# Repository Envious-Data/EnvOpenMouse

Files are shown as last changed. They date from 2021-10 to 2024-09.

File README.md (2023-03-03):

# EnvOpenMouse
 An Open-source mouse for the UK market.
 
### Why?

A lot of friends of mine would like something like a ploopyco mouse but there arent such options avaliable here in the UK and even then custom mouses as a whole is just not very popular.

This will be a open source mouse utilizting the PMW3360 and RP2040.

- Why the RP2040? Why not I say
- Why PMW3360 - its easiest to get and is well known by the community meaning resources are avaliable.

### To do
- Need to verify fit of everything
- firmware
- 3d printable housing
- housing/shell maybe can be made of other matierals
- perhaps write a guide on how to order and get everything made
- contact some vendors to sell this through for those who dont want self assembly

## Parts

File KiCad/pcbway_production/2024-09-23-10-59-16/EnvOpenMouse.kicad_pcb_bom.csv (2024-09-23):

Designator | Quantity | Value | Footprint | Package | MPN | DNP | Mount_Type | LCSC | Description | MANUFACTURER
C1, C4 | 2 | 22pf 0402 | C_0402_1005Metric |  |  |  | smt
C10, C11, C14, C15, C16, C17, C18, C19, C20, C7, C8 | 11 | 100nf 0402 | C_0402_1005Metric |  |  |  | smt
C12, C13, C6 | 3 | 1uf 0402 | C_0402_1005Metric |  |  |  | smt
C2 | 1 | 10uf 0402 6.3V | C_0402_1005Metric |  |  |  | smt
C3 | 1 | 10uf 0402 | C_0402_1005Metric |  |  |  | smt
C5 | 1 | 0.1uf 0402 | C_0402_1005Metric |  |  |  | smt
C9 | 1 | 4.7uf 0402 | C_0402_1005Metric |  |  |  | smt
D1 | 1 | 1n5819W | D_SOD-123 |  |  |  | smt
FLASH1 | 1 | W25Q16JVUXIQ | SON-8-1EP_3x2mm_P0.5mm_EP1.4x1.6mm |  |  |  | smt
H1, H2, H3, H4, H5, H5, H6, H6, H7, H8 | 10 | MountingHole_Pad | MountingHole_2.2mm_M2 |  |  |  | tht
J1, J3 | 2 | B3U-1000P | SW_Push_SPST_NO_Alps_SKRK |  |  |  | smt
J10, J12, J13, J14, J15, J9 | 6 | 0.8mm BM03B | JST_SUR_BM03B-SURS-TF_1x03-1MP_P0.80mm_Vertical |  |  |  | smt
J11 | 1 | Conn_02x02 Pins | PinHeader_1x02_P1.27mm_Vertical |  |  |  | tht
J16 | 1 | Conn_01x14 | PinHeader_1x14_P1.00mm_Vertical |  |  |  | tht |  | Generic connector, single row, 01x14, script generated (kicad-library-utils/schlib/autogen/connector/)
J2 | 1 | Conn_01x03 | PinHeader_1x03_P1.27mm_Vertical |  |  |  | tht
J4 | 1 | Conn_02x02 Socket | PinSocket_1x02_P1.27mm_Vertical |  |  |  | tht
J5, J6 | 2 | Conn_02x02 Socket | PinSocket_2x02_P1.27mm_Vertical |  |  |  | tht
J7, J8 | 2 | Conn_02x02 Pins | PinHeader_2x02_P1.27mm_Vertical |  |  |  | tht
R1 | 1 | 39 ohm 0402 | R_0402_1005Metric |  |  |  | smt
R10 | 1 | 27Ohms 0402 Resistor | C_0402_1005Metric |  |  |  | smt
R2, R6 | 2 | 1K 0402 | R_0402_1005Metric |  |  |  | smt
R3 | 1 | 10k 0402 | R_0402_1005Metric |  |  |  | smt
R4, R7 | 2 | 10K 0402 | R_0402_1005Metric |  |  |  | smt
R5, R8 | 2 | 5.1K | R_0402_1005Metric |  |  |  | smt
R9 | 1 | 27Ohms 0402 Resistor | C_0402_1005Metric |  |  |  | smt
SW1, SW2, SW3 | 3 | Kailh GM switch | MouseSwitch |  |  |  | tht
SW4, SW5, SW6, SW7, SW8, SW9 | 6 | B3U-1000P | SW_SPST_B3U-1000P |  |  |  | smt
U1 | 1 | AP2112K-3.3 | SOT-23-5 |  |  |  | smt
U2 | 1 | TLV70218DBVR | SOT-23-5 |  |  |  | smt
U3 | 1 | RP2040 | RP2040-QFN-56 |  |  |  | smt
U4 | 1 | PMW3360DM-T2QU | DIP-16_W10.16mm |  |  |  | tht
VR1 | 1 | EC10E1220501 | TRIM_EC10E1220501 |  |  |  | tht |  |  | ALPS
Y1 | 1 | 3225_4P 12MHz | Crystal_SMD_3225-4Pin_3.2x2.5mm |  |  |  | smt
e1 | 1 | TYPE-C-31-M-12 | HRO-TYPE-C-31-M-12 |  |  |  | smt

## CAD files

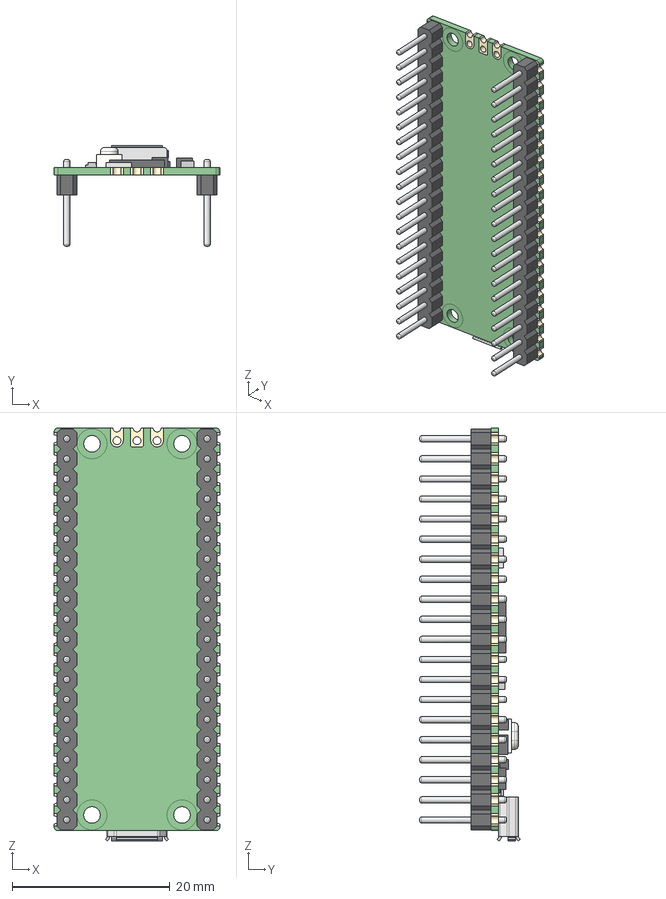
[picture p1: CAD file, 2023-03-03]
KiCad/3d/PICO_PinsDown.STEP
21.0 x 12.7 x 52.3 mm
PICO_REF_BOARD.STEP
PICO_REF_USB.STEP
PICO_REF_SWITCH.STEP
PICO_REF_MICROCONTROLLER.STEP
PICO_REF_LED.STEP
PICO_REF_ONSEMI.STEP
PICO_BOURNS.STEP
PICO_MURATA.STEP x 2
PICO_RICHTEK.STEP
PICO_DIODES.STEP
PICO_AEL.STEP
PICO_PIN_HEADERS
PICO_HEADER_HOLES

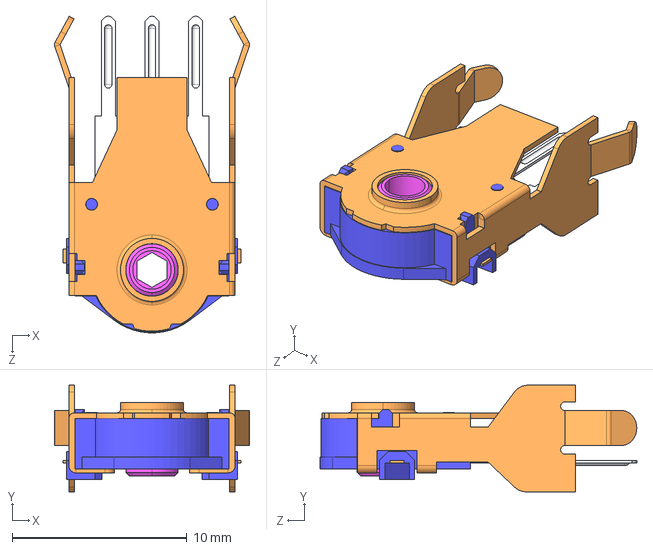
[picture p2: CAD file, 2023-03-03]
KiCad/3d/EC10E1260507.STEP
11.1 x 6.10 x 18.1 mm

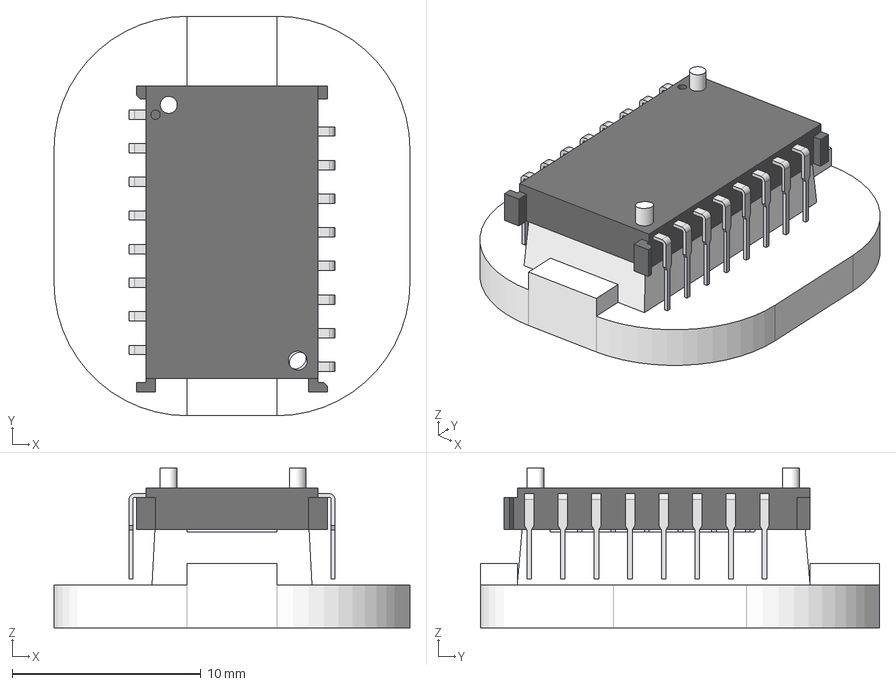
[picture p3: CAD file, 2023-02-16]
KiCad/3d/PMW3360.step
18.9 x 21.1 x 8.46 mm
Lead x 8
Lead(Mirror) x 8
Lens

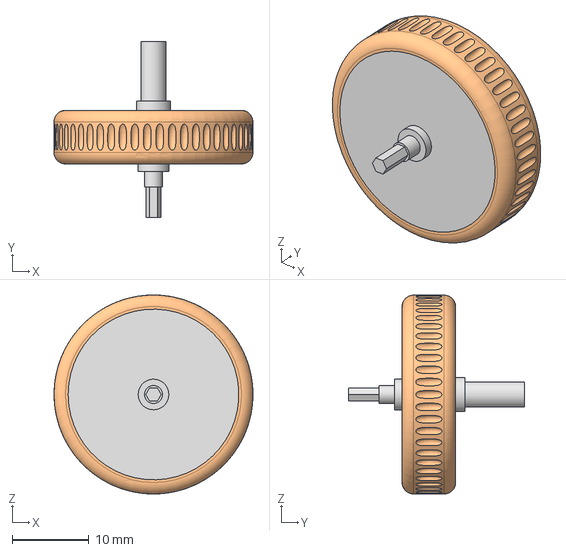
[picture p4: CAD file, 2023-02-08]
KiCad/3d/Sensei Scroll Wheel.step
26.0 x 23.0 x 26.0 mm

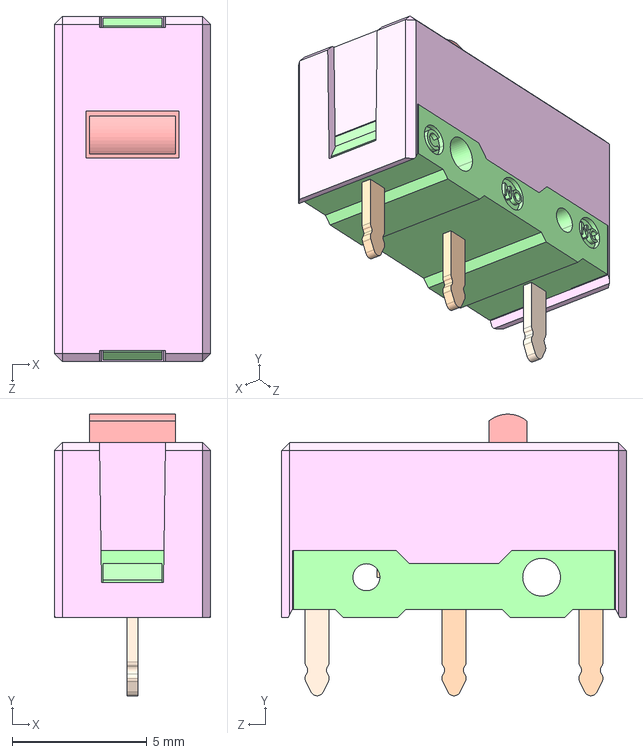
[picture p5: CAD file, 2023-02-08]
KiCad/3d/SWITCH_MOUSE.STEP
5.80 x 10.4 x 12.8 mm

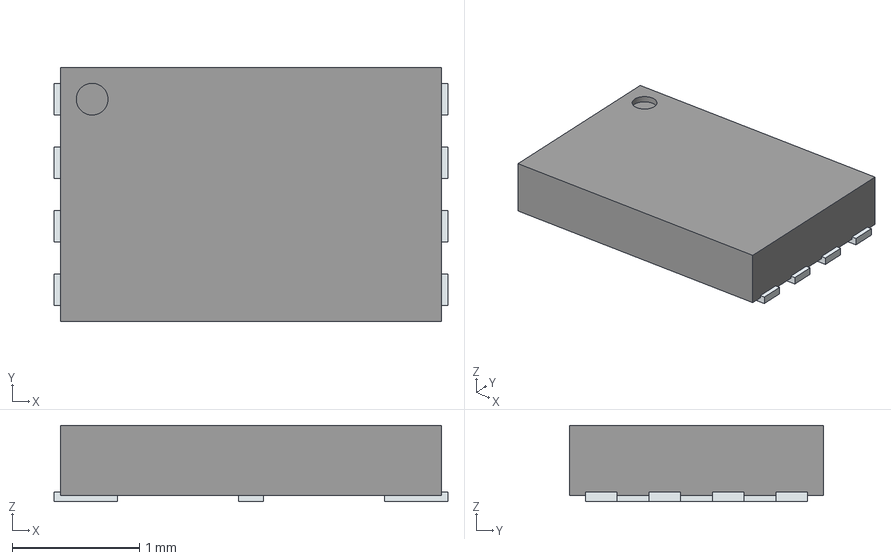
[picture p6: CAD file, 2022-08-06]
KiCad/3d/W25Q16JVUXIQ_TR.stp
3.10 x 2.00 x 0.6 mm
ThermalPin
PinsArrayLR

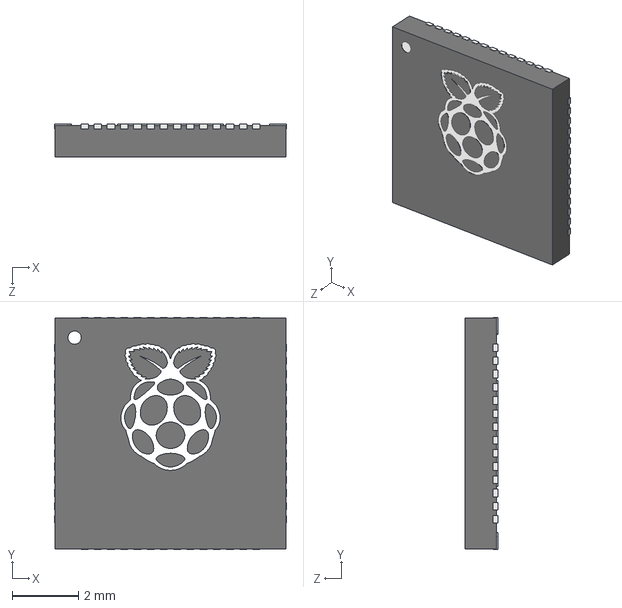
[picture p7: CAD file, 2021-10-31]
KiCad/3d/RP2040_QFN_PACKAGE.STEP
7.02 x 7.02 x 1.00 mm

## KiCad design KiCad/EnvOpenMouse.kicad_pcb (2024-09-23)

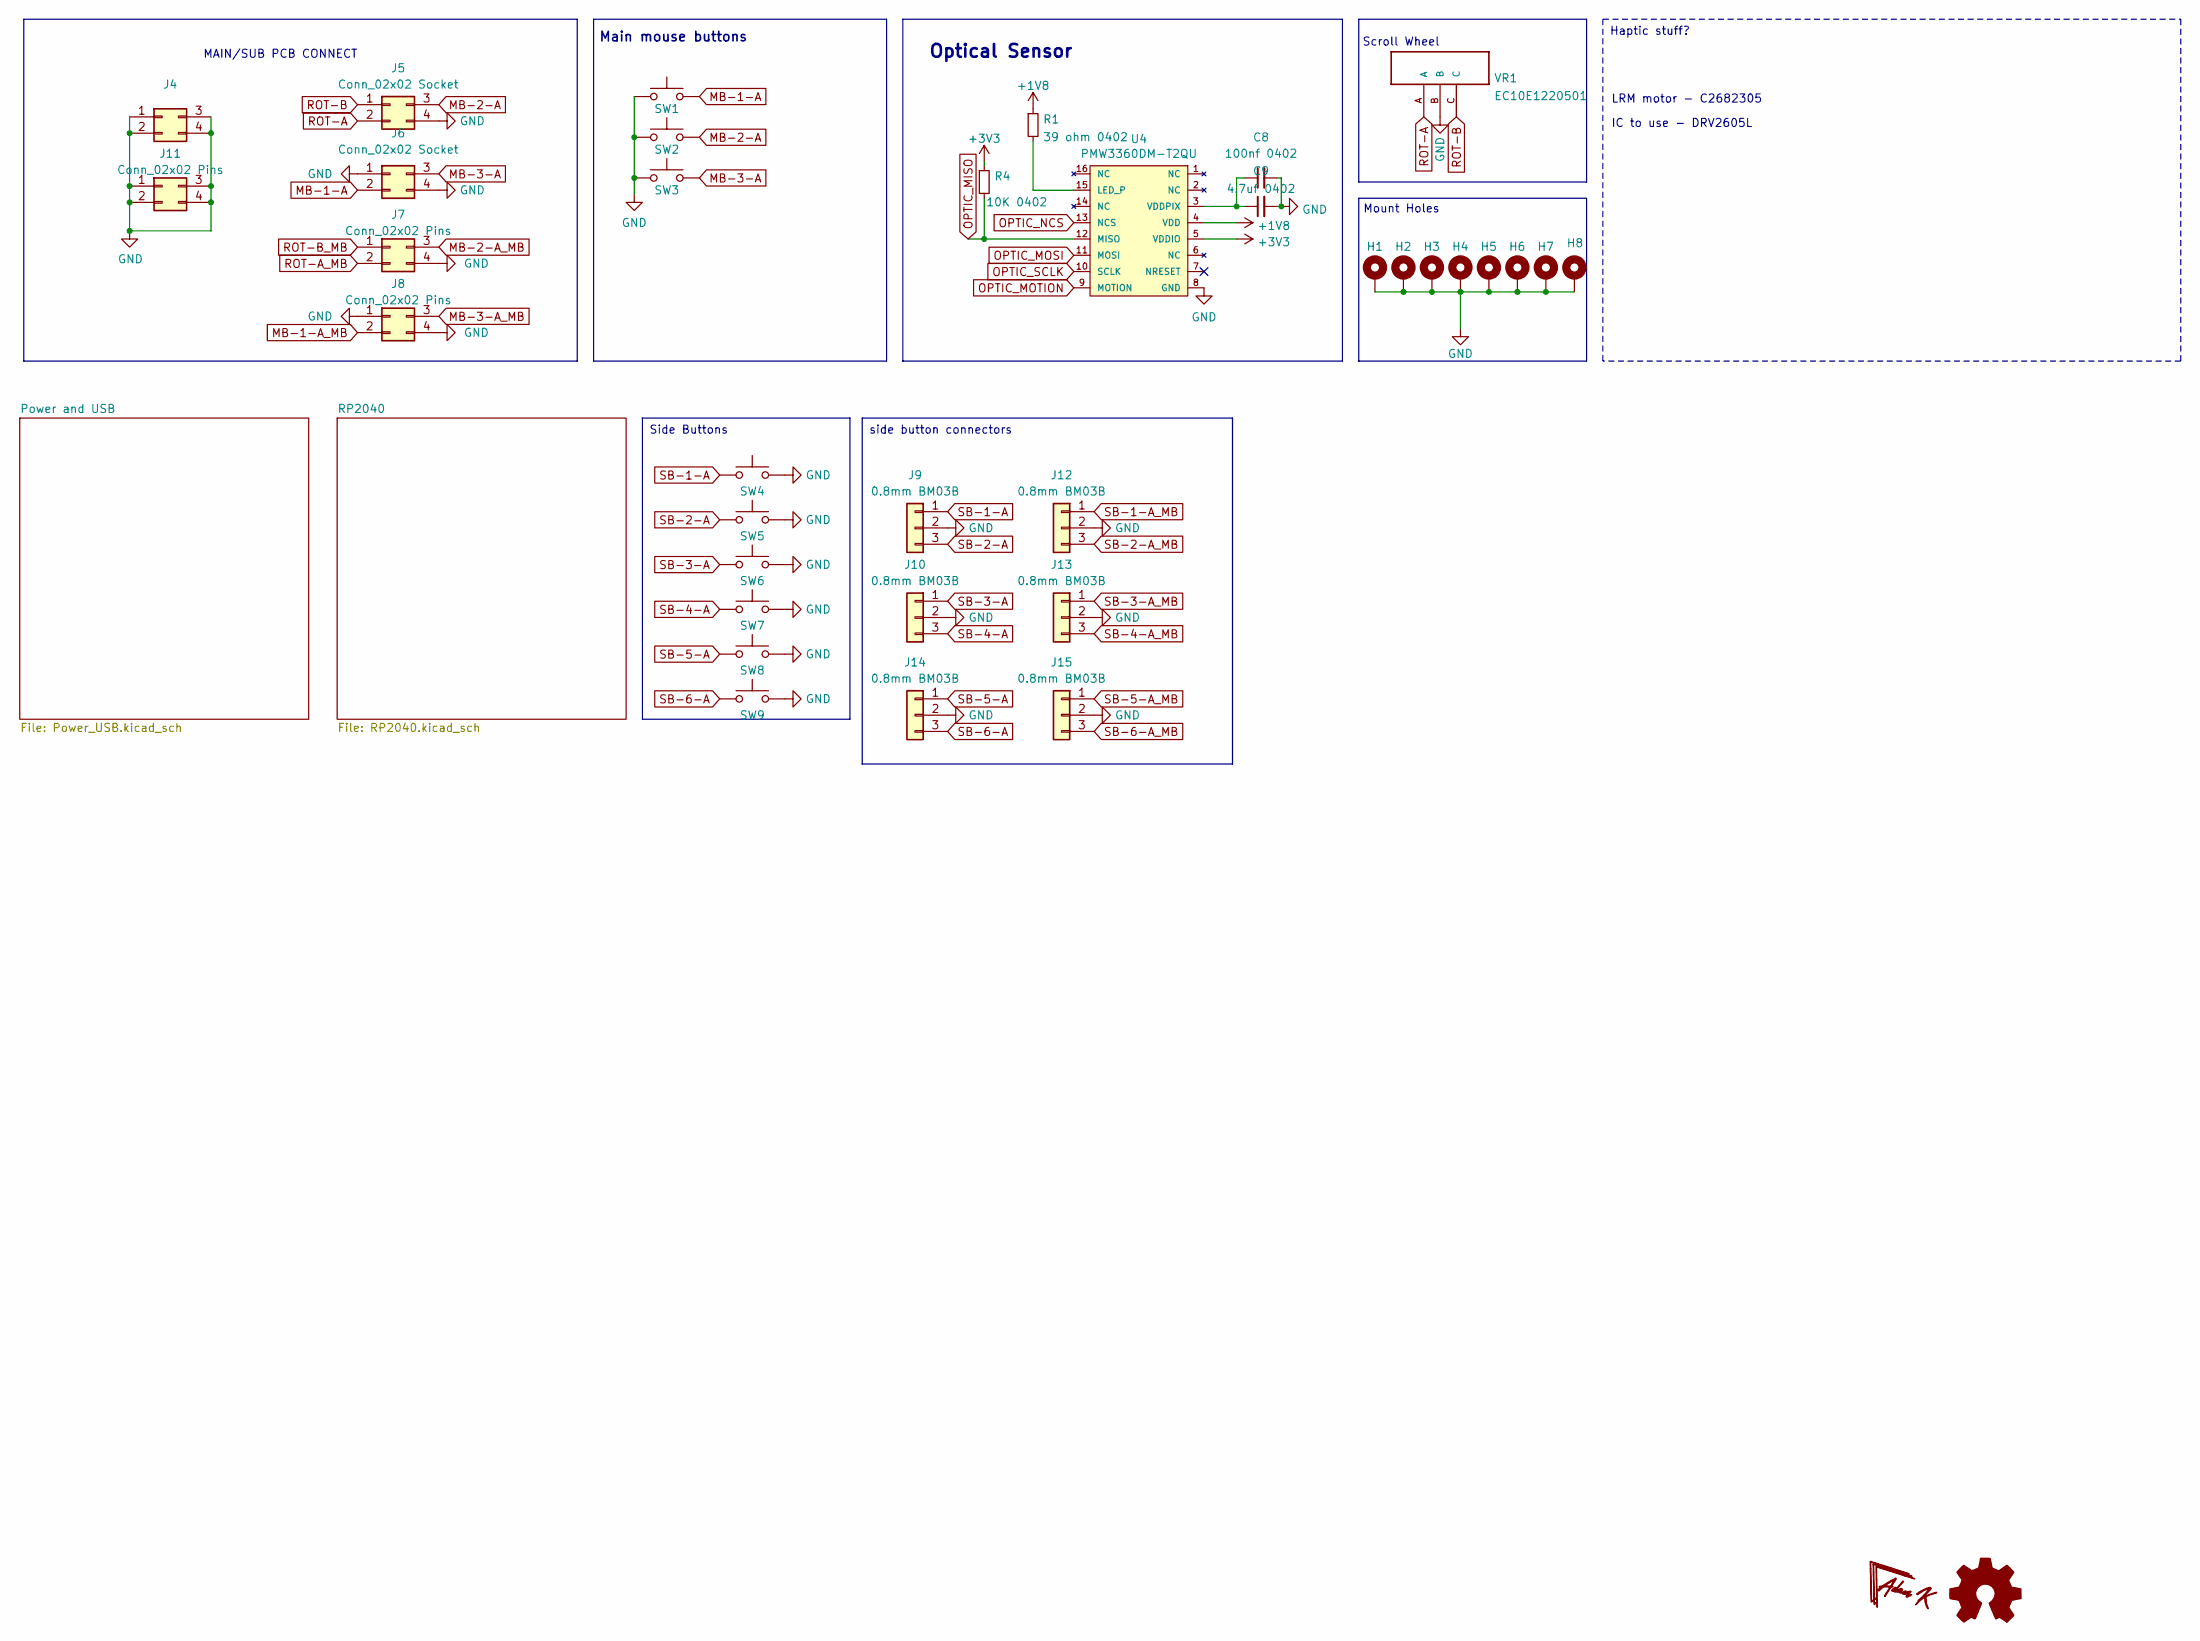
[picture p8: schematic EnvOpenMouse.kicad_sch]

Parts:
C8: 100nf 0402; C_0402_1005Metric
C9: 4.7uf 0402; C_0402_1005Metric
H1, H2, H3, H4, H5, H6, H7, H8: MountingHole_Pad; MountingHole_2.2mm_M2
J4: Conn_02x02 Socket; PinSocket_1x02_P1.27mm_Vertical
J5, J6: Conn_02x02 Socket; PinSocket_2x02_P1.27mm_Vertical
J7, J8: Conn_02x02 Pins; PinHeader_2x02_P1.27mm_Vertical
J9, J10, J12, J13, J14, J15: 0.8mm BM03B; JST_SUR_BM03B-SURS-TF_1x03-1MP_P0.80mm_Vertical
J11: Conn_02x02 Pins; PinHeader_1x02_P1.27mm_Vertical
R1: 39 ohm 0402; R_0402_1005Metric
R4: 10K 0402; R_0402_1005Metric
SW1, SW2, SW3: Kailh GM switch; MouseSwitch
SW4, SW5, SW6, SW7, SW8, SW9: B3U-1000P; SW_SPST_B3U-1000P
U4: PMW3360DM-T2QU; DIP-16_W10.16mm
VR1: EC10E1220501; TRIM_EC10E1220501

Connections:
+1V8: R1.1, U4.4 (VDD); also elsewhere on the board
+3V3: R4.1, U4.5 (VDDIO); also elsewhere on the board
GND: C8.2, C9.2, H1.1, H2.1, H3.1, H4.1, H5.1, H6.1, H7.1, H8.1, J4.1, J4.2, J4.3, J4.4, J5.4, J6.1, J6.4, J7.4, J8.1, J8.4, J9.2, J10.2, J11.1, J11.2, J11.3, J11.4, J12.2, J13.2, J14.2, J15.2, SW1.1, SW2.1, SW3.1, SW4.1, SW5.1, SW6.1, SW7.1, SW8.1, SW9.1, U4.8 (GND), VR1.B; also elsewhere on the board
MB-1-A: J6.2, SW1.2
MB-1-A_MB: J8.2; also elsewhere on the board
MB-2-A: J5.3, SW2.2
MB-2-A_MB: J7.3; also elsewhere on the board
MB-3-A: J6.3, SW3.2
MB-3-A_MB: J8.3; also elsewhere on the board
unnamed: R1.2, U4.15 (LED_P)
unnamed: C8.1, C9.1, U4.3 (VDDPIX)
OPTIC_MISO: R4.2, U4.12 (MISO); also elsewhere on the board
OPTIC_MOSI: U4.11 (MOSI); also elsewhere on the board
OPTIC_MOTION: U4.9 (MOTION); also elsewhere on the board
OPTIC_NCS: U4.13 (NCS); also elsewhere on the board
OPTIC_SCLK: U4.10 (SCLK); also elsewhere on the board
ROT-A: J5.2, VR1.A
ROT-A_MB: J7.2; also elsewhere on the board
ROT-B: J5.1, VR1.C
ROT-B_MB: J7.1; also elsewhere on the board
SB-1-A: J9.1, SW4.2
SB-1-A_MB: J12.1; also elsewhere on the board
SB-2-A: J9.3, SW5.2
SB-2-A_MB: J12.3; also elsewhere on the board
SB-3-A: J10.1, SW6.2
SB-3-A_MB: J13.1; also elsewhere on the board
SB-4-A: J10.3, SW7.2
SB-4-A_MB: J13.3; also elsewhere on the board
SB-5-A: J14.1, SW8.2
SB-5-A_MB: J15.1; also elsewhere on the board
SB-6-A: J14.3, SW9.2
SB-6-A_MB: J15.3; also elsewhere on the board

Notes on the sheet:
Side Buttons
side button connectors
Haptic stuff?
MAIN/SUB PCB CONNECT
Scroll Wheel
LRM motor - C2682305
Main mouse buttons
IC to use - DRV2605L
Optical Sensor
Mount Holes

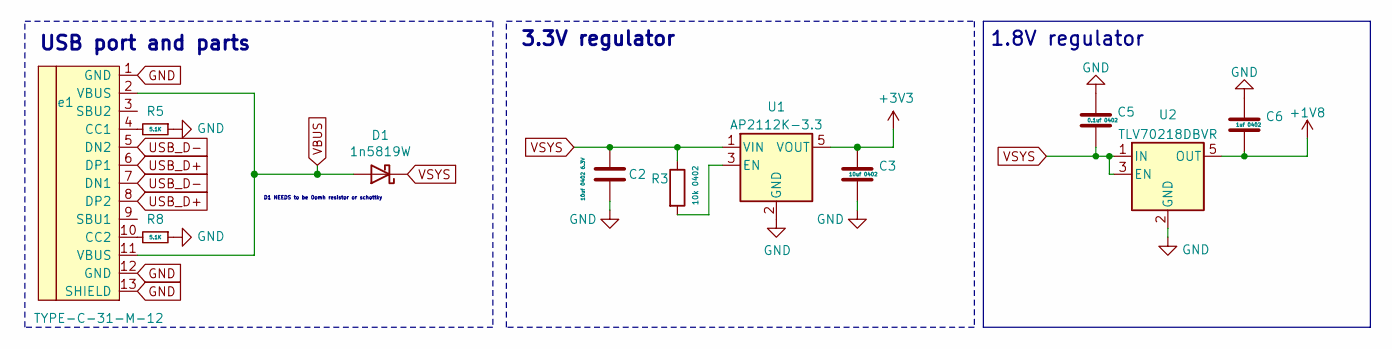
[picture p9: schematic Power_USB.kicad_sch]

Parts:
C2: 10uf 0402 6.3V; C_0402_1005Metric
C3: 10uf 0402; C_0402_1005Metric
C5: 0.1uf 0402; C_0402_1005Metric
C6: 1uf 0402; C_0402_1005Metric
D1: 1n5819W; D_SOD-123
R3: 10k 0402; R_0402_1005Metric
R5, R8: 5.1K; R_0402_1005Metric
U1: AP2112K-3.3; SOT-23-5
U2: TLV70218DBVR; SOT-23-5
e1: TYPE-C-31-M-12; HRO-TYPE-C-31-M-12

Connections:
+1V8: C6.2, U2.5 (OUT); also elsewhere on the board
+3V3: C3.1, U1.5 (VOUT); also elsewhere on the board
GND: C2.2, C3.2, C5.1, C6.1, R5.1, R8.1, U1.2 (GND), U2.2 (GND), e1.1 (GND), e1.12 (GND), e1.13 (SHIELD); also elsewhere on the board
unnamed: R3.2, U1.3 (EN)
unnamed: R5.2, e1.4 (CC1)
unnamed: R8.2, e1.10 (CC2)
USB_D+: e1.6 (DP1), e1.8 (DP2); also elsewhere on the board
USB_D-: e1.5 (DN2), e1.7 (DN1); also elsewhere on the board
VBUS: D1.2 (A), e1.2 (VBUS), e1.11 (VBUS)
VSYS: C2.1, C5.2, D1.1 (K), R3.1, U1.1 (VIN), U2.1 (IN), U2.3 (EN)

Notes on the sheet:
1.8V regulator
3.3V regulator
USB port and parts
D1 NEEDS to be 0omh resistor or schottky

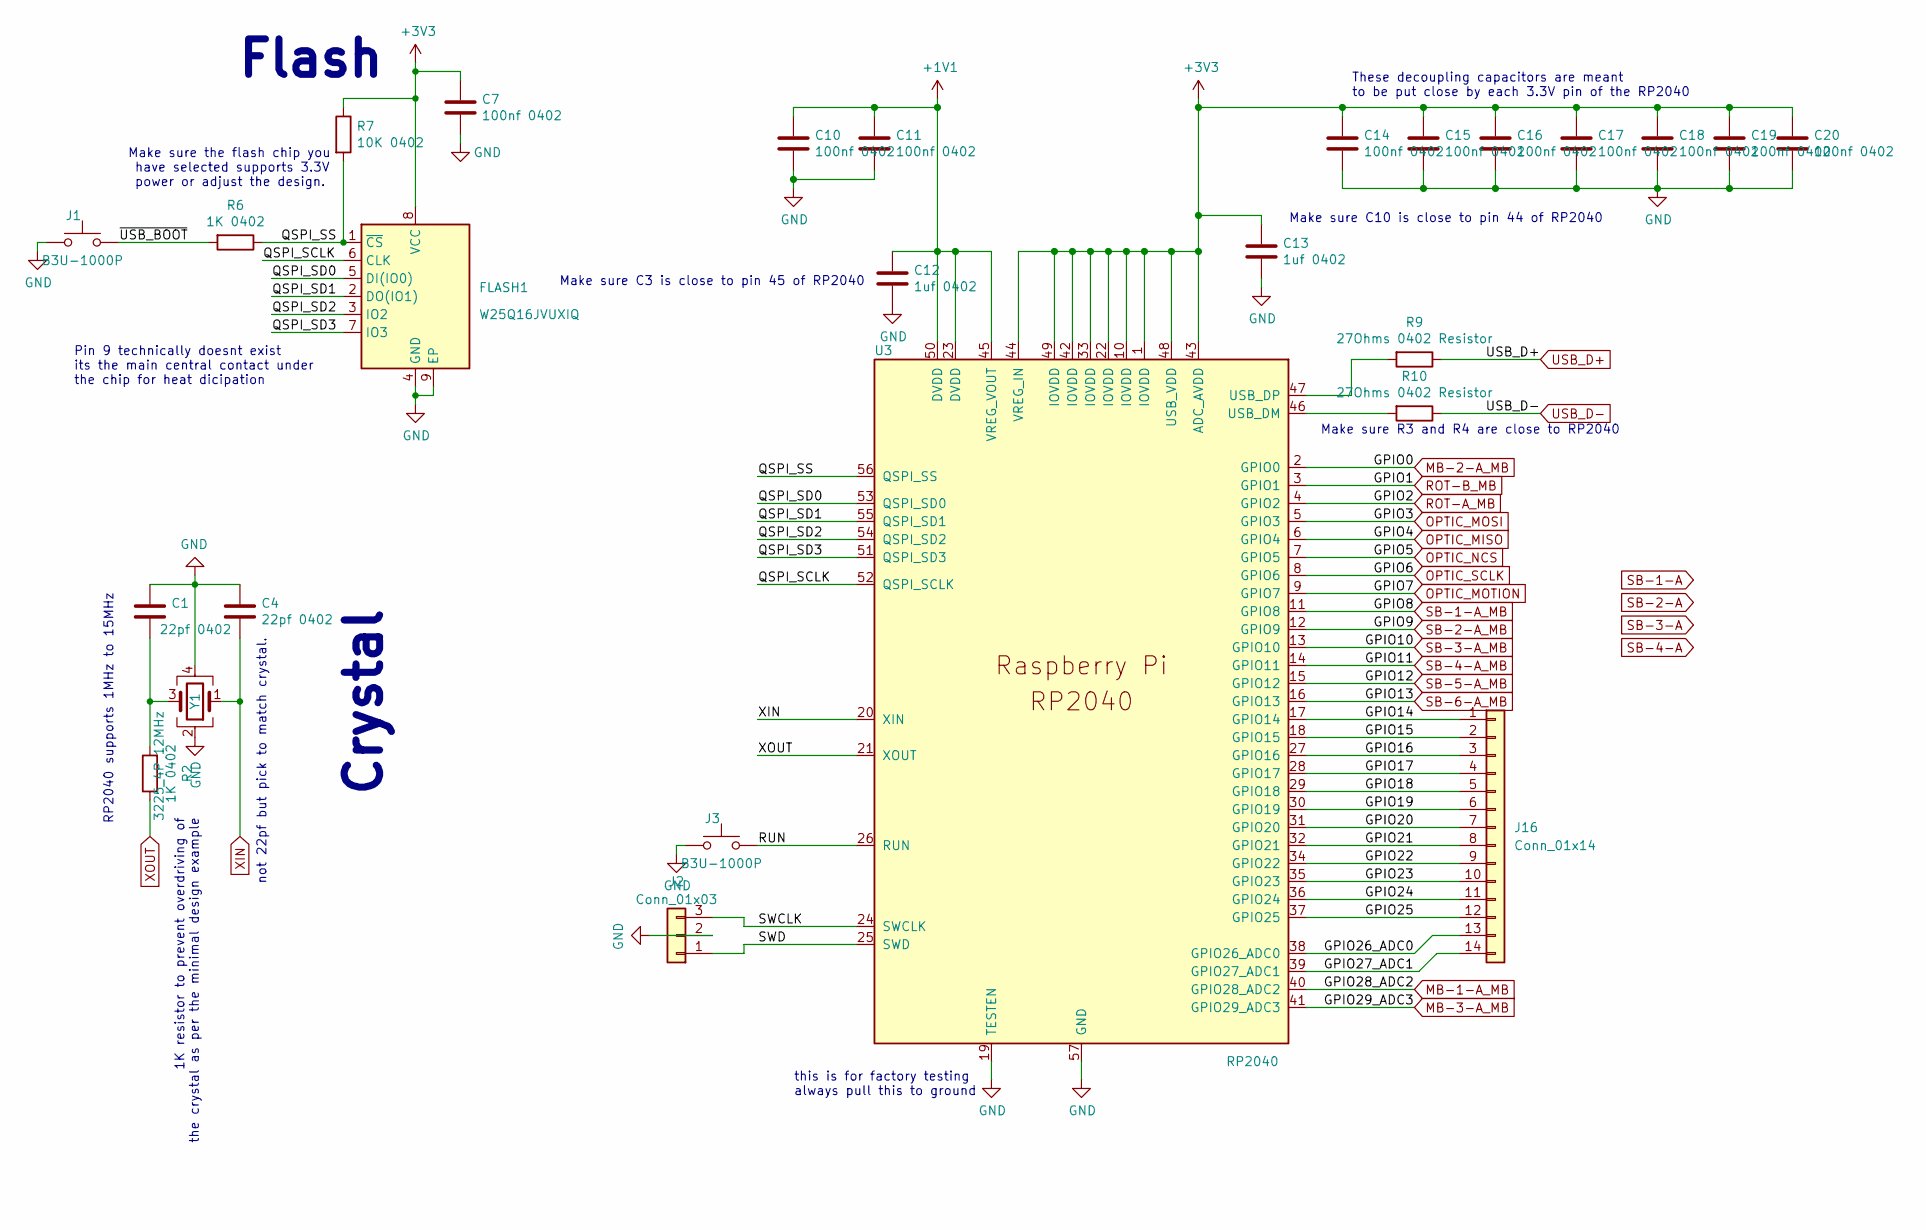
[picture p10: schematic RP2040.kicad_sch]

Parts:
C1, C4: 22pf 0402; C_0402_1005Metric
C7, C10, C11, C14, C15, C16, C17, C18, C19, C20: 100nf 0402; C_0402_1005Metric
C12, C13: 1uf 0402; C_0402_1005Metric
FLASH1: W25Q16JVUXIQ; SON-8-1EP_3x2mm_P0.5mm_EP1.4x1.6mm
J1, J3: B3U-1000P; SW_Push_SPST_NO_Alps_SKRK
J2: Conn_01x03; PinHeader_1x03_P1.27mm_Vertical
J16: Conn_01x14; PinHeader_1x14_P1.00mm_Vertical
R2, R6: 1K 0402; R_0402_1005Metric
R7: 10K 0402; R_0402_1005Metric
R9, R10: 27Ohms 0402 Resistor; C_0402_1005Metric
U3: RP2040; RP2040-QFN-56
Y1: 3225_4P 12MHz; Crystal_SMD_3225-4Pin_3.2x2.5mm

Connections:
+1V1: C10.1, C11.1, C12.1, U3.23 (DVDD), U3.45 (VREG_VOUT), U3.50 (DVDD)
+3V3: C7.1, C13.1, C14.1, C15.1, C16.1, C17.1, C18.1, C19.1, C20.1, FLASH1.8 (VCC), R7.1, U3.1 (IOVDD), U3.10 (IOVDD), U3.22 (IOVDD), U3.33 (IOVDD), U3.42 (IOVDD), U3.43 (ADC_AVDD), U3.44 (VREG_IN), U3.48 (USB_VDD), U3.49 (IOVDD); also elsewhere on the board
/RP2040/GPIO14: J16.1, U3.17 (GPIO14)
/RP2040/GPIO15: J16.2, U3.18 (GPIO15)
/RP2040/GPIO16: J16.3, U3.27 (GPIO16)
/RP2040/GPIO17: J16.4, U3.28 (GPIO17)
/RP2040/GPIO18: J16.5, U3.29 (GPIO18)
/RP2040/GPIO19: J16.6, U3.30 (GPIO19)
/RP2040/GPIO20: J16.7, U3.31 (GPIO20)
/RP2040/GPIO21: J16.8, U3.32 (GPIO21)
/RP2040/GPIO22: J16.9, U3.34 (GPIO22)
/RP2040/GPIO23: J16.10, U3.35 (GPIO23)
/RP2040/GPIO24: J16.11, U3.36 (GPIO24)
/RP2040/GPIO25: J16.12, U3.37 (GPIO25)
/RP2040/GPIO26_ADC0: J16.13, U3.38 (GPIO26_ADC0)
/RP2040/GPIO27_ADC1: J16.14, U3.39 (GPIO27_ADC1)
/RP2040/QSPI_SCLK: FLASH1.6 (CLK), U3.52 (QSPI_SCLK)
/RP2040/QSPI_SD0: FLASH1.5 (DI(IO0)), U3.53 (QSPI_SD0)
/RP2040/QSPI_SD1: FLASH1.2 (DO(IO1)), U3.55 (QSPI_SD1)
/RP2040/QSPI_SD2: FLASH1.3 (IO2), U3.54 (QSPI_SD2)
/RP2040/QSPI_SD3: FLASH1.7 (IO3), U3.51 (QSPI_SD3)
/RP2040/QSPI_SS: FLASH1.1 (~CS), R6.1, R7.2, U3.56 (QSPI_SS)
/RP2040/RUN: J3.1, U3.26 (RUN)
/RP2040/SWCLK: J2.3, U3.24 (SWCLK)
/RP2040/SWD: J2.1, U3.25 (SWD)
/RP2040/~USB_BOOT: J1.1, R6.2
GND: C1.1, C4.1, C7.2, C10.2, C11.2, C12.2, C13.2, C14.2, C15.2, C16.2, C17.2, C18.2, C19.2, C20.2, FLASH1.4 (GND), FLASH1.9 (EP), J1.2, J2.2, J3.2, U3.19 (TESTEN), U3.57 (GND), Y1.2, Y1.4; also elsewhere on the board
MB-1-A_MB: U3.40 (GPIO28_ADC2); also elsewhere on the board
MB-2-A_MB: U3.2 (GPIO0); also elsewhere on the board
MB-3-A_MB: U3.41 (GPIO29_ADC3); also elsewhere on the board
unnamed: C1.2, R2.2, Y1.3
unnamed: R10.2, U3.46 (USB_DM)
unnamed: R9.2, U3.47 (USB_DP)
OPTIC_MISO: U3.6 (GPIO4); also elsewhere on the board
OPTIC_MOSI: U3.5 (GPIO3); also elsewhere on the board
OPTIC_MOTION: U3.9 (GPIO7); also elsewhere on the board
OPTIC_NCS: U3.7 (GPIO5); also elsewhere on the board
OPTIC_SCLK: U3.8 (GPIO6); also elsewhere on the board
ROT-A_MB: U3.4 (GPIO2); also elsewhere on the board
ROT-B_MB: U3.3 (GPIO1); also elsewhere on the board
SB-1-A_MB: U3.11 (GPIO8); also elsewhere on the board
SB-2-A_MB: U3.12 (GPIO9); also elsewhere on the board
SB-3-A_MB: U3.13 (GPIO10); also elsewhere on the board
SB-4-A_MB: U3.14 (GPIO11); also elsewhere on the board
SB-5-A_MB: U3.15 (GPIO12); also elsewhere on the board
SB-6-A_MB: U3.16 (GPIO13); also elsewhere on the board
USB_D+: R9.1; also elsewhere on the board
USB_D-: R10.1; also elsewhere on the board
XIN: C4.2, U3.20 (XIN), Y1.1
XOUT: R2.1, U3.21 (XOUT)

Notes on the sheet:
Make sure C10 is close to pin 44 of RP2040
1K resistor to prevent overdriving of the crystal as per the minimal design example
Crystal
Make sure R3 and R4 are close to RP2040
this is for factory testing always pull this to ground
Make sure C3 is close to pin 45 of RP2040
Pin 9 technically doesnt exist its the main central contact under the chip for heat dicipation
not 22pf but pick to match crystal.
These decoupling capacitors are meant to be put close by each 3.3V pin of the RP2040
Make sure the flash chip you have selected supports 3.3V power or adjust the design.
Flash
RP2040 supports 1MHz to 15MHz

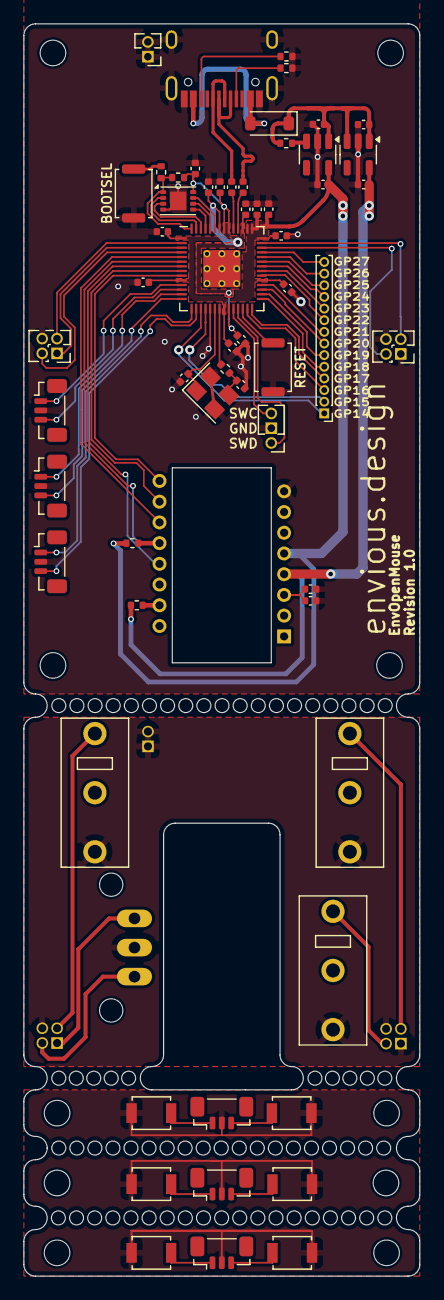
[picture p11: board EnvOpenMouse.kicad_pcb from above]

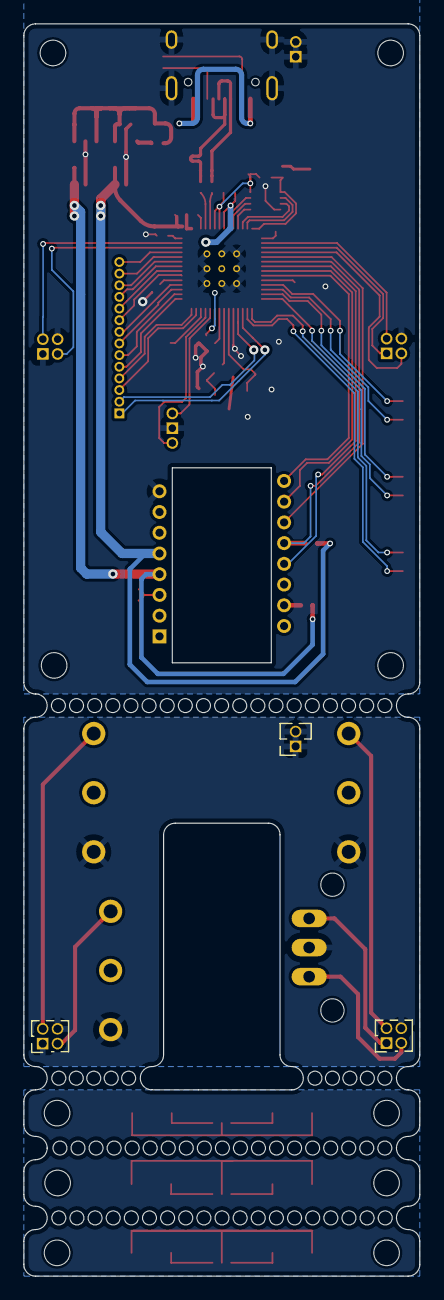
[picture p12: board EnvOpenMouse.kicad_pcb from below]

Board: 2 copper layers, 34.0 x 107.5 mm, 74 parts (3 on the bottom side), 69 nets.

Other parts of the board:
H5#2, H6#2: MountingHole_Pad; MountingHole_2.2mm_M2

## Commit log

2021-10-30 Initial commit +1
    [sensor.kicad_pcb, sensor.kicad_sch]
2021-10-30 added mouse switch footprint.
2021-10-30 added license, some small tweaks and all.
    [sensor.kicad_pcb, sensor.kicad_sch]
2021-10-31 Decided redo PCB
    [sensor.kicad_pcb, sensor.kicad_sch]
2021-10-31 Fillet :cat2:
    [sensor.kicad_pcb]
2021-10-31 added rotary encoder to the schematic
    [sensor.kicad_pcb, sensor.kicad_sch]
2021-10-31 Renamed KiCad Project Appropriately
    [EnvOpenMouse.kicad_pcb, EnvOpenMouse.kicad_sch]
2021-10-31 added some GPIO headers
    [EnvOpenMouse.kicad_pcb, EnvOpenMouse.kicad_sch]
2021-10-31 adjusted silkscreen markings and some traces.
    [EnvOpenMouse.kicad_pcb]
2021-11-22 swapped button bits for some GPIO headers
    [EnvOpenMouse.kicad_pcb, EnvOpenMouse.kicad_sch]
2022-01-07 decided to overhaul this project a bit
    [EnvOpenMouse.kicad_pcb, EnvOpenMouse.kicad_sch]
2022-01-09 small fix
    [EnvOpenMouse.kicad_pcb, EnvOpenMouse.kicad_sch]
2022-01-28 added missing capactor and middle click button.
    [EnvOpenMouse.kicad_pcb, EnvOpenMouse.kicad_sch]
2022-08-06 Appended RP2040 to board, begin work on Mouse PCB
    [EnvOpenMouse.kicad_pcb, EnvOpenMouse.kicad_sch, RP2040MCU.kicad_sch]
2022-08-06 routed onboard MCU
    [EnvOpenMouse.kicad_pcb, EnvOpenMouse.kicad_sch, RP2040MCU.kicad_sch]
2022-08-27 I dont even remember what I changed.
    [EnvOpenMouse.kicad_pcb, EnvOpenMouse.kicad_sch, RP2040MCU.kicad_sch]
2023-02-08 decided to work on this again | made PCB have reasonableish dimensions and moved mouse buttons to suitable positions
    [EnvOpenMouse.kicad_pcb, EnvOpenMouse.kicad_sch, RP2040MCU.kicad_sch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]
2023-02-08 routed some more traces
    [EnvOpenMouse.kicad_pcb, EnvOpenMouse.kicad_sch, RP2040MCU.kicad_sch]
2023-02-16 ran traces for parts previously left disconnected and moved about some to improve ease of routing and also shortened PCB down to 94mm along with slimmed width + mount holes
    [EnvOpenMouse.kicad_pcb, EnvOpenMouse.kicad_sch, PMW3360.step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]
2023-03-03 adjusted position of some parts and re-routed related traces, might do that again to compact everything
    [EnvOpenMouse.kicad_pcb]
2023-03-03 Decided to re-design the whole board again but with a pico so perhaps I can fit a PicoW and maybe make a BLE version
    [EC10E1260507.STEP, EnvOpenMouse.kicad_pcb, EnvOpenMouse.kicad_sch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]
2023-03-04 routed and adjusted various traces and component positions
    [EnvOpenMouse.kicad_pcb, EnvOpenMouse.kicad_sch]
2023-03-13 overhauled design and generated gerbers
    [EnvOpenMouse.kicad_pcb, EnvOpenMouse.kicad_sch, EnvOpenMouse_bom_jlc.csv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]
2023-03-13 corrected some issues and updated gerbers
    [EnvOpenMouse.kicad_pcb, EnvOpenMouse.kicad_sch, EnvOpenMouse_bom_jlc.csv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]
2023-03-19 corrected some issues with the design + added fpc/ffc for cirque glidepoint
    [EnvOpenMouse.kicad_pcb, EnvOpenMouse.kicad_sch]
2023-10-06 commit changes I forgot to commit, unsure of what it contains
    [EnvOpenMouse_bom_jlc.csv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]
2024-04-04 re-worked PCB to remove wireless support and battery charge IC
    [EnvOpenMouse.kicad_pcb, EnvOpenMouse.kicad_sch]
2024-04-04 forgot to remove some silkscreen
    [EnvOpenMouse.kicad_pcb]
2024-05-16 removed a bunch of headers, added proper zones for 3v3 and 1v1, would like to add 4x side buttons
    [EnvOpenMouse.kicad_pcb, EnvOpenMouse.kicad_sch]
2024-06-02 redid all traces, adjusted schematic, pinouts, added some side buttons.
    [EnvOpenMouse.kicad_pcb, EnvOpenMouse.kicad_sch, Power_USB.kicad_sch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]
2024-06-07 swapped some 3d models
    [EnvOpenMouse.kicad_pcb, RP2040_QFN_PACKAGE.STEP]
2024-06-18 Added missing connections.
    [EnvOpenMouse.kicad_pcb, RP2040.kicad_sch]
2024-09-12 double checked board and tidied things up.
    [EnvOpenMouse.kicad_pcb, EnvOpenMouse.kicad_sch, Power_USB.kicad_sch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]
2024-09-18 downsized main board, added more buttons and respective connector, improved spacing of various power traces
    [EnvOpenMouse.kicad_pcb, EnvOpenMouse.kicad_sch, RP2040.kicad_sch]
2024-09-18 added header for unused GPIOs
    [EnvOpenMouse.kicad_pcb, RP2040.kicad_sch]
2024-09-18 generated production files
    [EnvOpenMouse.kicad_pcb, EnvOpenMouse.kicad_sch, bom.csv]
2024-09-19 final cleanups and other fixes
    [EnvOpenMouse.kicad_pcb, EnvOpenMouse.kicad_sch, Power_USB.kicad_sch]
2024-09-23 updated part values, generated production files
    [EnvOpenMouse.kicad_pcb, EnvOpenMouse.kicad_pcb_bom.csv, EnvOpenMouse.kicad_sch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]
2024-09-23 generated fixes production files
    [EnvOpenMouse.kicad_pcb, EnvOpenMouse.kicad_pcb_bom.csv, EnvOpenMouse.kicad_sch]
